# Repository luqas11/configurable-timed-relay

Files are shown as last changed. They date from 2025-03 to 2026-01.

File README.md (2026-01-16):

# configurable-timed-relay

### What is this

This project includes the firmware, circuit, and case design for a **system that powers AC electric appliances daily, at a user-defined fixed time and duration**. The user sets the schedule through a webpage served with an **ESP8266** based board, which is synchronized with the current time over internet and activates a relay module at the required hour to power the output. A 3D printed case allows a compact mounting of the involved components and wiring, along with lights to visually indicate the system status. A simple web portal allows the user to configure the WiFi where the device should connect to.

### Screenshots
#### Main page:
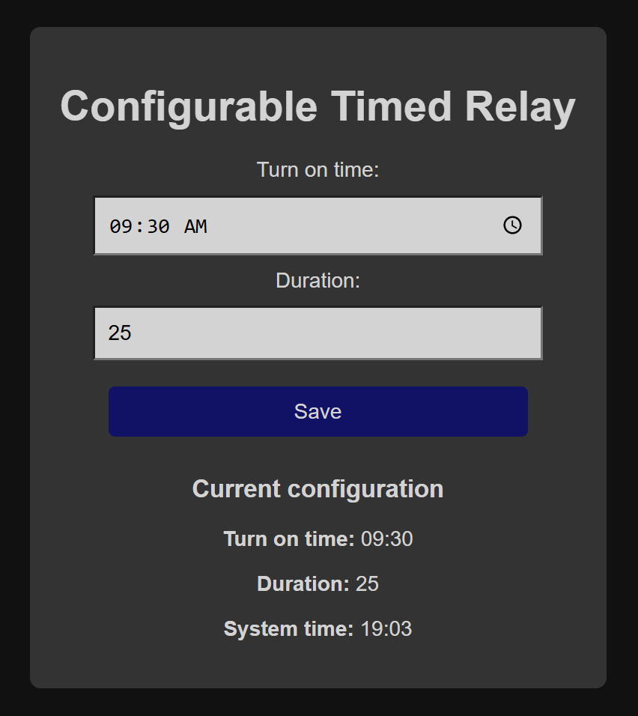
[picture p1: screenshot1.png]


#### WiFi configuration page:
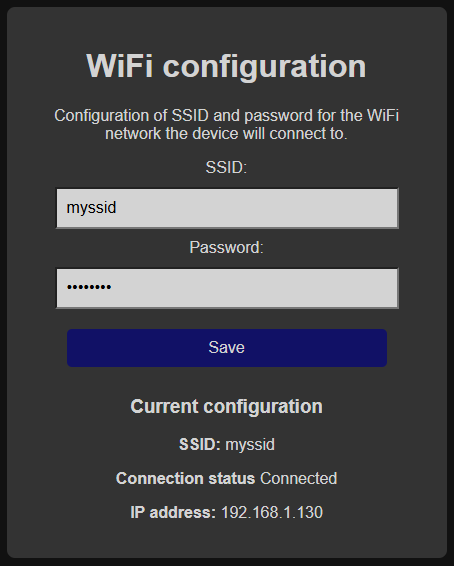
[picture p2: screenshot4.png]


#### Circuit schematic:
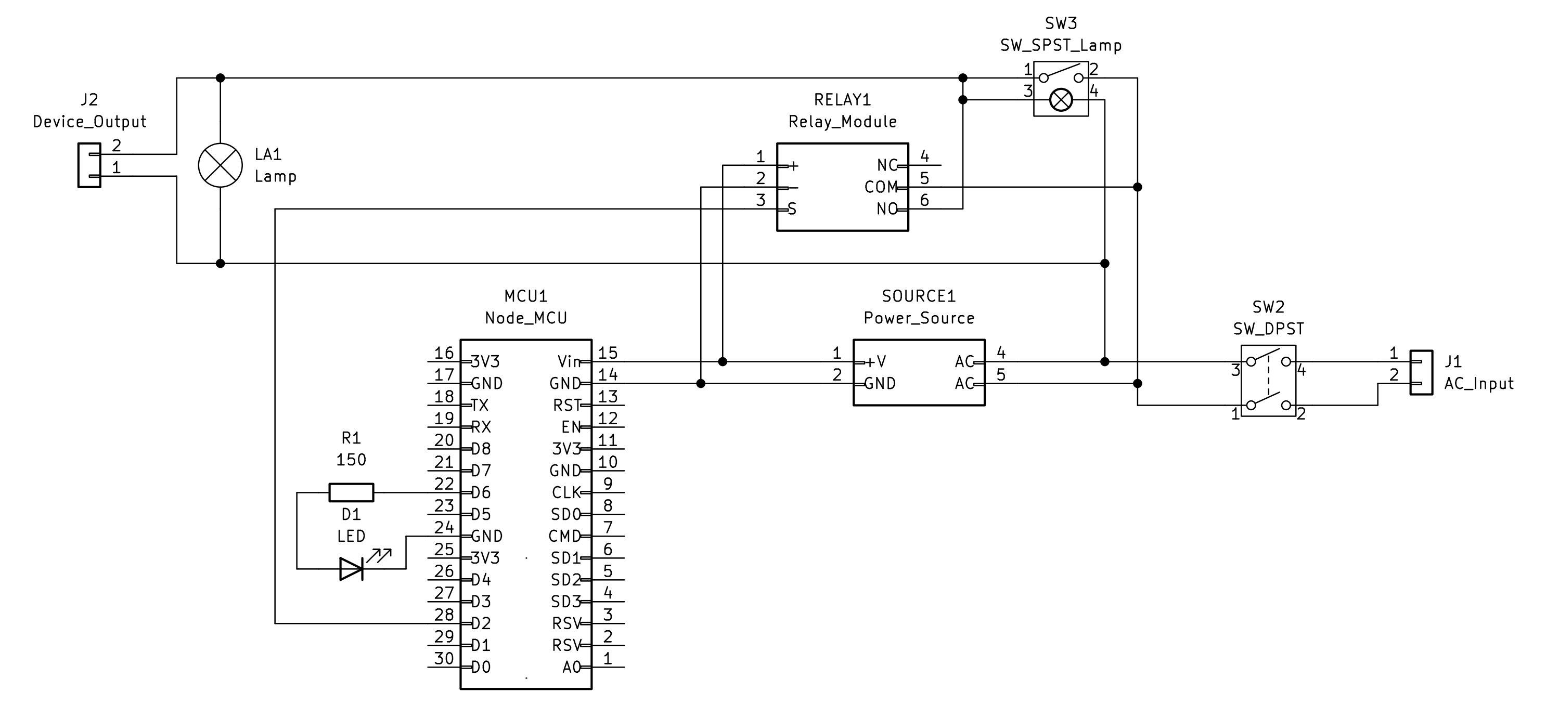
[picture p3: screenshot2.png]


#### Case 3D model:
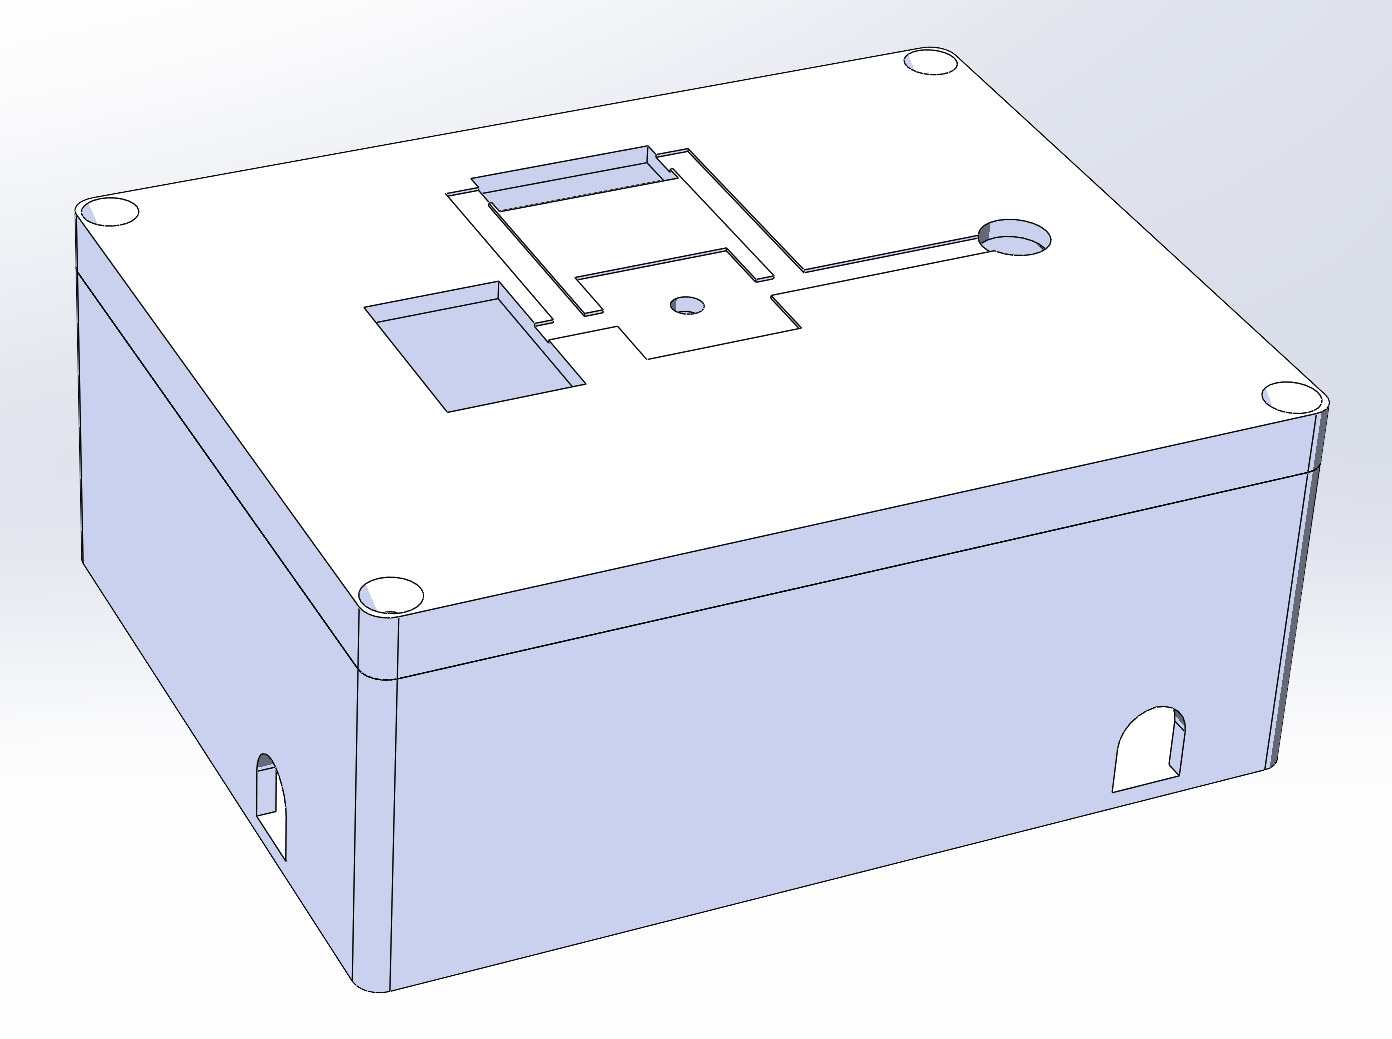
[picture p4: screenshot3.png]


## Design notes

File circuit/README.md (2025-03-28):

# Circuit
This is the wiring diagram to connect the **ESP** board to the power source, relay module and switches. A schematic plot can be seen in the `circuit-schematic.pdf` file. The box 3D models are in the `Box.STL` and `Lid.STL` files.

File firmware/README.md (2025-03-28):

# Firmware

### How this works
This ESP8266 sketch connects the board to the WiFi network, and fetches the current time periodically using the [Arduino Time Library](https://github.com/PaulStoffregen/Time). When the configured time matches the current time, the board turns on the relay modules for the specified duration. The configuration values can be set from a webpage server at the board's IP, which exchanges information dynamically with it through exposed endpoints.

### API

`[GET] /get-values`  

Returns the current configured values, with the time in minutes and the duration in seconds. For example:
```
{
    "time": 570,
    "duration": 30
}
```

`[GET] /set-values?time={time}&duration={duration}`  

Sets the configures values, with the time in minutes and the duration in seconds. The given name can only contain numbers, and be lesser than some defined maximums. For example, the query params could be:
```
/set-values?time=1048&duration=25
```

`[GET] /get-current-hour`  

Returns the current system hour in minutes. For example:
```
{
    "currentHour": "1035"
}
```

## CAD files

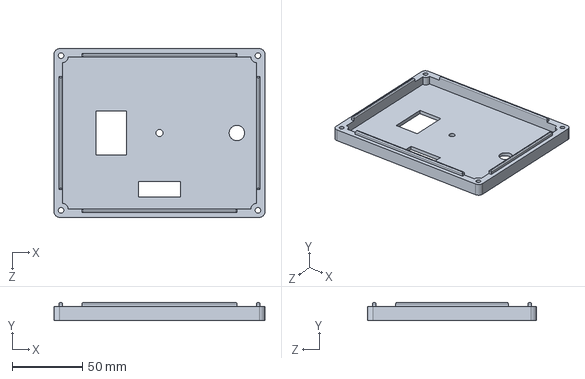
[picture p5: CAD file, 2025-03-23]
circuit/Lid.SLDPRT
150.0 x 13.0 x 120.0 mm

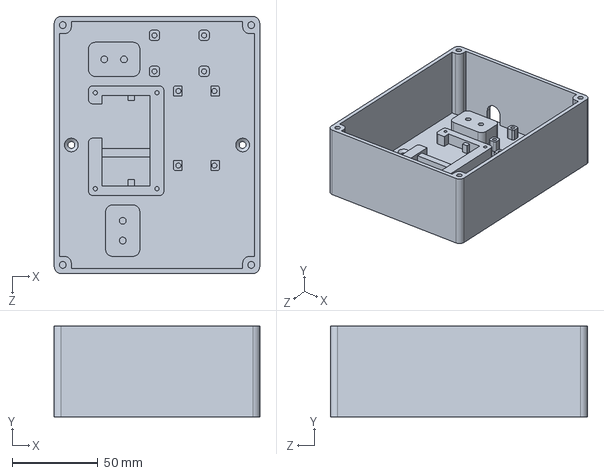
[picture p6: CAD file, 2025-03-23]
circuit/Box.SLDPRT
120.0 x 53.0 x 150.0 mm

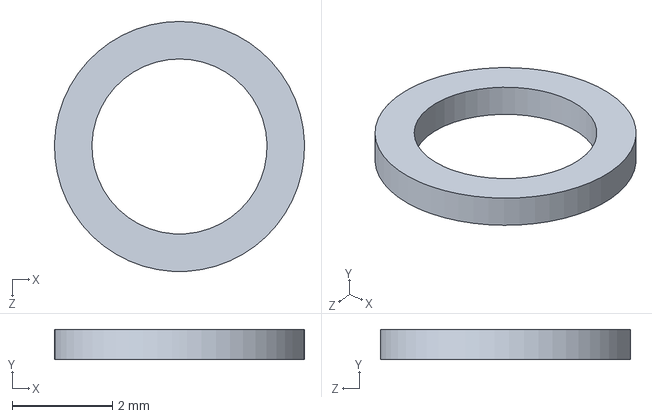
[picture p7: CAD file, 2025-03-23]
circuit/Washer.SLDPRT
5.00 x 0.6 x 5.00 mm

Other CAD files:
circuit/Box.STL
circuit/Lid.STL
circuit/Washer.STL

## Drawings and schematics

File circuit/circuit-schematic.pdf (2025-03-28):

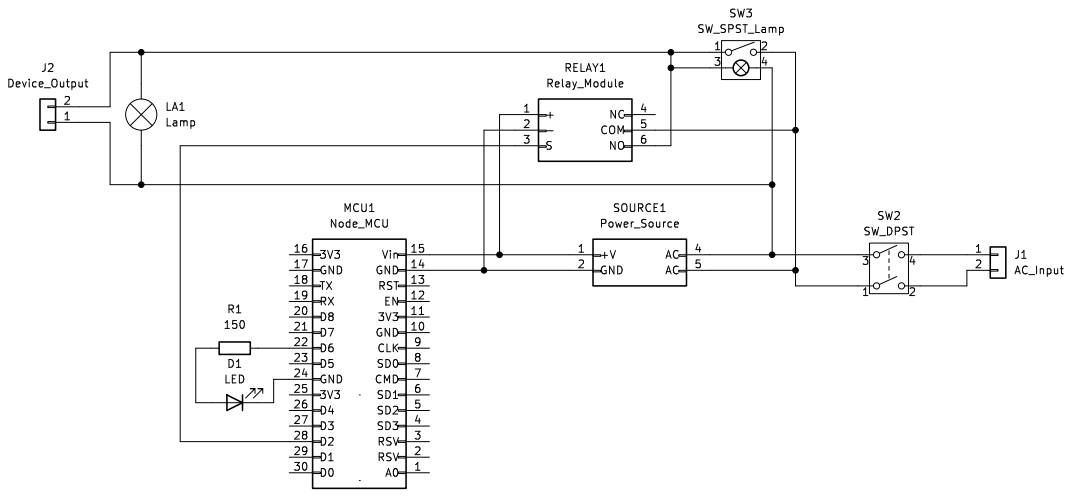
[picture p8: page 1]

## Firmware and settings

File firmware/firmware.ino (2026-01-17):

#include <ESP8266WebServer.h>
#include <ESP8266WiFi.h>
#include <ArduinoJson.h>
#include "EEPROMUtils.h"
#include "WiFiUtils.h"
#include "TimeUtils.h"
#include "config.h"
#include "AdminPage.h"
#include "IndexPage.h"

/*
   Version 1.1.0
   17-1-2026

   External libraries:
   ArduinoJson@7.4.2
   esp8266@3.1.2
   Time@1.6.1
*/

// Duration of the status LED blinks
const int LED_BLINK_TIME = 100;

// Outputs pin numbers
int STATUS_LED = 12;
int RELAY_PIN = 4;

// Memory addresses
const int TIME_ADDR = 0;
const int DURATION_ADDR = 1;

// Maximum configurable values
const int MAX_TIME = 60 * 24;
const int MAX_DURATION = 600;

// State variables
unsigned long lastLedTimestamp;
bool isLedBlinking;
int currentTime = -1;
int currentDuration = -1;
unsigned long turnOffTimestamp;
bool hasAlreadyRun;

// HTTP server instance
ESP8266WebServer server(80);

void setup() {
  // Initialize output pins
  pinMode(STATUS_LED, OUTPUT);
  pinMode(RELAY_PIN, OUTPUT);
  digitalWrite(STATUS_LED, HIGH);
  digitalWrite(RELAY_PIN, LOW);

  // Initialize the serial communication, the EEPROM library, the WiFi connection and the Time library
  Serial.begin(9600);
  beginEEPROM();
  beginWiFi(SSID_AP, PASSWORD_AP, STATUS_LED);
  beginTime();

  // Read and validate the configured values from the EEPROM
  uint16_t _currentTime = readFromEEPROM(TIME_ADDR);
  uint16_t _currentDuration = readFromEEPROM(DURATION_ADDR);
  if (_currentTime < MAX_TIME) {
    currentTime = _currentTime;
  }
  if (_currentDuration < MAX_DURATION) {
    currentDuration = _currentDuration;
  }

  // Set up all the server endpoints
  server.on("/", handleRoot);
  server.on("/admin", handleAdmin);
  server.on("/set-values", handleSetValues);
  server.on("/get-values", handleGetValues);
  server.on("/get-current-hour", handleGetCurrentHour);
  server.on("/get-wifi-config", handleGetWiFiConfig);
  server.on("/set-wifi-config", handleSetWiFiConfig);
  server.on("/get-wifi-status", handleGetWiFiStatus);
  server.onNotFound(handleNotFound);

  // Initialize the HTTP server
  server.begin();
}

void loop() {
  // Handle any incoming request, if exists
  server.handleClient();

  // Set the LED state depending on the network status
  if (isLedBlinking != true) {
    digitalWrite(STATUS_LED, isWiFiConnected() ? LOW : HIGH);
  }

  // Turn off the status LED if the blink is finished
  if ((millis() - lastLedTimestamp) > LED_BLINK_TIME && isLedBlinking == true) {
    digitalWrite(STATUS_LED, LOW);
    isLedBlinking = false;
  }

  // Check if the current minute is the confgured one
  if (isTimeSet() && (getCurrentHour() == currentTime / 60) && (getCurrentMinute() == currentTime % 60)) {
    // If the output hasn't been turned on yet, do it and update the state variables
    if (!hasAlreadyRun) {
      turnOffTimestamp = millis() + currentDuration * 1000;
      digitalWrite(RELAY_PIN, HIGH);
      hasAlreadyRun = true;
    }
  } else {
    // When the configured minute is over, and the output is off, update the state variable
    if (millis() > turnOffTimestamp) {
      hasAlreadyRun = false;
    }
  }

  // If the output timer is over, turn the output off
  if (millis() > turnOffTimestamp) {
    digitalWrite(RELAY_PIN, LOW);
  }
}

// Sets the configured values
void handleSetValues() {
  String time = server.arg("time");
  String duration = server.arg("duration");

  char *endTime;
  long newTime = strtol(time.c_str(), &endTime, 10);

  if (time == "" || *endTime != '\0' || newTime >= MAX_TIME || newTime < 0) {
    String response = formatError("ERR_01", "Invalid time value");
    server.send(400, "application/json", response);
    blinkStatusLed();
    return;
  }

  char *endDuration;
  long newDuration = strtol(duration.c_str(), &endDuration, 10);

  if (duration == "" || *endDuration != '\0' || newDuration >= MAX_DURATION || newDuration <= 0) {
    String response = formatError("ERR_02", "Invalid duration value");
    server.send(400, "application/json", response);
    blinkStatusLed();
    return;
  }

  writeToEEPROM(TIME_ADDR, newTime);
  writeToEEPROM(DURATION_ADDR, newDuration);
  currentTime = newTime;
  currentDuration = newDuration;

  server.send(200);
  blinkStatusLed();
}

// Gets the configured values
void handleGetValues() {
  if (currentTime == -1 || currentDuration == -1) {
    String response = formatError("ERR_04", "Cannot get the configured values");
    server.send(500, "application/json", response);
    blinkStatusLed();
    return;
  }

  String response;
  StaticJsonDocument<128> doc;

  doc["time"] = currentTime;
  doc["duration"] = currentDuration;
  serializeJson(doc, response);

  server.send(200, "application/json", response);
  blinkStatusLed();
}

// Gets the current system hour
void handleGetCurrentHour() {
  if (!isTimeSet()) {
    String response = formatError("ERR_03", "The system hour is not set");
    server.send(500, "application/json", response);
    blinkStatusLed();
    return;
  }

  String response;
  StaticJsonDocument<128> doc;

  doc["currentHour"] = getCurrentHour() * 60 + getCurrentMinute();
  serializeJson(doc, response);

  server.send(200, "application/json", response);
  blinkStatusLed();
}

// Sets the WiFi configuration
void handleSetWiFiConfig() {
  String ssid = server.arg("ssid");
  String password = server.arg("password");

  if (ssid == "" || ssid.length() > 32) {
    String response = formatError("ERR_05", "Invalid WiFi SSID");
    server.send(400, "application/json", response);
    blinkStatusLed();
    return;
  }

  if (password == "" || password.length() < 8 || password.length() > 64) {
    String response = formatError("ERR_06", "Invalid WiFi password");
    server.send(400, "application/json", response);
    blinkStatusLed();
    return;
  }

  WiFi.begin(ssid, password);

  server.send(200);
  blinkStatusLed();

  connectToWiFi(STATUS_LED);
  if (isWiFiConnected()) {
    forceTimeSync();
  }
}

// Gets the WiFi configuration
void handleGetWiFiConfig() {
  String response;
  StaticJsonDocument<128> doc;

  doc["ssid"] = WiFi.SSID();
  serializeJson(doc, response);

  server.send(200, "application/json", response);
  blinkStatusLed();
}

// Gets the current WiFi status
void handleGetWiFiStatus() {
  String response;
  StaticJsonDocument<128> doc;

  doc["status"] = WiFi.status();
  doc["ip"] = WiFi.localIP().isSet() ? WiFi.localIP().toString() : "";
  serializeJson(doc, response);

  server.send(200, "application/json", response);
  blinkStatusLed();
}

// Returns a not found message to the client, formatted as a JSON string
void handleNotFound() {
  String response = formatError("ERR_00", "URL not found");
  server.send(404, "application/json", response);
  blinkStatusLed();
}

// Returns an HTML page to the client, to manage and see the system configuration
void handleRoot() {
  server.send(200, "text/html", INDEX_HTML);
  blinkStatusLed();
}

// Returns an HTML page to the client, to manage and see the WiFi configuration
void handleAdmin() {
  server.send(200, "text/html", ADMIN_HTML);
  blinkStatusLed();
}

// Set the status LED to blink, updating it's state variables
void blinkStatusLed() {
  digitalWrite(STATUS_LED, HIGH);
  lastLedTimestamp = millis();
  isLedBlinking = true;
}

// Creates a JSON string with an error code and an error message values.
String formatError(String errorCode, String errorMessage) {
  String response;
  StaticJsonDocument<128> doc;

  doc["error_code"] = errorCode;
  doc["error_message"] = errorMessage;

  serializeJson(doc, response);
  return response;
}

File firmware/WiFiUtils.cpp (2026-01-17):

#include "WiFiUtils.h"
#include <ESP8266WiFi.h>

const int MAX_AWAIT_TIME = 15;

bool isWiFiConnected() {
  return WiFi.status() == WL_CONNECTED;
}

void beginWiFi(String ssidAP, String passwordAP, int ledPin) {
  WiFi.mode(WIFI_AP_STA);
  WiFi.begin();
  WiFi.softAP(ssidAP, passwordAP);
  WiFi.persistent(true);
  connectToWiFi(ledPin);
}

void connectToWiFi(int ledPin) {
  Serial.println("Connecting to WiFi");
  for (int i = 0; i < MAX_AWAIT_TIME; i++) {
    if (isWiFiConnected()) {
      break;
    }
    digitalWrite(ledPin, LOW);
    delay(500);
    Serial.print(".");
    digitalWrite(ledPin, HIGH);
    delay(500);
  }
  Serial.println();

  if (isWiFiConnected()) {
    Serial.println("WiFi connected");
    Serial.println("IP address: ");
    Serial.println(WiFi.localIP());
  } else {
    Serial.println("WiFi connection failed");
  }
}

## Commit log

2025-03-03 Add timer and relay logic
2025-03-23 Fix wrong output states
    [firmware.ino]
2025-03-23 Add circuit case models
    [Box.SLDPRT, Box.STL, Lid.SLDPRT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]
2025-03-28 Add circuit schematic
    [circuit.kicad_pcb, circuit.kicad_sch]
2025-03-28 Add project screenshots
    [circuit.kicad_sch]
2026-01-16 Add current IP text to WiFi configuration page
2026-01-17 Modify blinking times to make them more identifiable and fix minor frontend bugs
    [WiFiUtils.cpp, firmware.ino]
